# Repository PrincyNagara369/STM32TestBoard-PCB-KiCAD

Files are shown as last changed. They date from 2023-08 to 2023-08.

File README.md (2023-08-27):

# STM32TestBoard-PCB-KiCAD
Creating a PCB design for an STM32 test board using KiCad involves several steps. Below is a general outline of the process:

1. **Install KiCad:**
   If you haven't already, download and install the KiCad software from the official KiCad website (https://www.kicad-pcb.org/download/).

2. **Create a New Project:**
   - Open KiCad and create a new project for your STM32 test board.
   - Choose a suitable project name and location.

3. **Schematic Design:**
   - Start by creating a new schematic sheet in your project.
   - Add components to the schematic, including the STM32 microcontroller, power supply components, connectors, and any other peripherals you plan to include.
   - Connect the components by adding wires and creating appropriate nets.

4. **Component Libraries:**
   - Make sure you have the required component libraries for your components. KiCad comes with a set of default libraries, and you can also download additional libraries if needed.

5. **Footprint Assignment:**
   - Associate footprints with your schematic symbols. KiCad allows you to associate each component with a physical footprint used in the PCB layout.

6. **Schematic Annotation:**
   - Annotate the components on the schematic. KiCad will assign unique reference designators (e.g., U1, R1) to each component.

7. **Electrical Rule Check (ERC):**
   - Run an ERC to identify any potential connectivity or design rule errors in your schematic.

8. **Generate Netlist:**
   - Generate a netlist file from your schematic. The netlist is used to create the PCB layout.

9. **PCB Layout:**
   - Create a new PCB layout from the generated netlist.
   - Import footprints for your components or create custom footprints if necessary.
   - Place the components on the PCB layout, arranging them in a logical and organized manner.

10. **Connect Traces:**
    - Route the traces to connect the components according to your design.
    - Pay attention to signal integrity, power distribution, and ground plane.

11. **Design Rules Check (DRC):**
    - Run a DRC to ensure that your layout adheres to design rules such as minimum trace width, clearance, and other manufacturing specifications.

12. **Add Copper Pours and Planes:**
    - Create copper pours for power and ground connections.
    - Add ground and power planes if necessary for better signal integrity and noise reduction.

13. **3D Visualization:**
    - KiCad provides a 3D visualization tool that lets you preview your PCB in a realistic manner.

14. **Generate Gerber Files:**
    - Once you're satisfied with your PCB layout, generate the necessary Gerber files for manufacturing. These files include information about copper traces, solder mask, silkscreen, and more.

15. **Assembly Drawing:**
    - Create an assembly drawing that shows the component placements, reference designators, and other important details for assembling the PCB.

16. **Final Checks:**
    - Review your design thoroughly to ensure everything is correct and meets your requirements.

17. **Documentation:**
    - Create a documentation package that includes the schematic, PCB layout files, Gerber files, and any additional notes or instructions.

18. **Manufacturing:**
    - Send the Gerber files and other required documents to a PCB manufacturer for fabrication.

Remember that PCB design can be complex and requires attention to detail. It's also a good practice to consult the datasheets and reference manuals of your components, as well as any relevant PCB design guidelines from the microcontroller manufacturer. Additionally, there are many online resources, tutorials, and forums where you can find help and guidance during your KiCad PCB design journey.

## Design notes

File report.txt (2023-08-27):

Info: Reading netlist file 'C:\Users\Princy\Desktop\STM32F4_REV2\STM32F4_REV2.net'.

Info: Using reference designators to match symbols and footprints.

Info: Processing symbol 'J1:TerminalBlock_Phoenix:TerminalBlock_Phoenix_PT-1,5-2-3.5-H_1x02_P3.50mm_Horizontal'.
Info: Processing symbol 'R9:Resistor_SMD:R_0603_1608Metric'.
Info: Processing symbol 'R6:Resistor_SMD:R_0603_1608Metric'.
Info: Processing symbol 'R5:Resistor_SMD:R_0603_1608Metric'.
Info: Processing symbol 'R4:Resistor_SMD:R_0603_1608Metric'.
Info: Processing symbol 'R3:Resistor_SMD:R_0603_1608Metric'.
Info: Processing symbol 'R2:Resistor_SMD:R_0603_1608Metric'.
Info: Processing symbol 'R1:Resistor_SMD:R_0603_1608Metric'.
Info: Processing symbol 'R10:Resistor_SMD:R_0402_1005Metric'.
Info: Processing symbol 'R11:Resistor_SMD:R_0402_1005Metric'.
Info: Processing symbol 'R8:Resistor_SMD:R_0402_1005Metric'.
Info: Processing symbol 'R7:Resistor_SMD:R_0402_1005Metric'.
Info: Processing symbol 'U3:Package_TO_SOT_SMD:SOT-23-6'.
Info: Processing symbol 'U1:Package_TO_SOT_SMD:SOT-23-6'.
Info: Processing symbol 'Q1:Package_TO_SOT_SMD:SOT-23'.
Info: Processing symbol 'U2:Package_QFP:LQFP-64_10x10mm_P0.5mm'.
Info: Processing symbol 'H1:MountingHole:MountingHole_4.3mm_M4_Pad_Via'.
Info: Processing symbol 'H2:MountingHole:MountingHole_4.3mm_M4_Pad_Via'.
Info: Processing symbol 'H3:MountingHole:MountingHole_4.3mm_M4_Pad_Via'.
Info: Processing symbol 'H4:MountingHole:MountingHole_4.3mm_M4_Pad_Via'.
Info: Processing symbol 'D3:LED_SMD:LED_0603_1608Metric'.
Info: Processing symbol 'D4:LED_SMD:LED_0603_1608Metric'.
Info: Processing symbol 'L1:Inductor_SMD:L_Sunlord_MWSA0518S'.
Info: Processing symbol 'FB1:Inductor_SMD:L_0805_2012Metric'.
Info: Processing symbol 'L2:Inductor_SMD:L_0402_1005Metric'.
Info: Processing symbol 'F1:Fuse:Fuse_1206_3216Metric'.
Info: Processing symbol 'D2:Diode_SMD:D_SOD-123'.
Info: Processing symbol 'D1:Diode_SMD:D_SOD-123'.
Info: Processing symbol 'Y1:Crystal:Crystal_SMD_3225-4Pin_3.2x2.5mm'.
Info: Processing symbol 'J5:Connector_USB:USB_Micro-B_GCT_USB3076-30-A'.
Info: Processing symbol 'J2:Connector_PinSocket_1.27mm:PinSocket_2x05_P1.27mm_Vertical_SMD'.
Info: Processing symbol 'J3:Connector_Molex:Molex_PicoBlade_53048-0410_1x04_P1.25mm_Horizontal'.
Info: Processing symbol 'J4:Connector_Molex:Molex_PicoBlade_53048-0410_1x04_P1.25mm_Horizontal'.
Info: Processing symbol 'C1:Capacitor_SMD:C_1206_3216Metric'.
Info: Processing symbol 'C2:Capacitor_SMD:C_1206_3216Metric'.
Info: Processing symbol 'C3:Capacitor_SMD:C_1206_3216Metric'.
Info: Processing symbol 'C4:Capacitor_SMD:C_0603_1608Metric'.
Info: Processing symbol 'C14:Capacitor_SMD:C_0603_1608Metric'.
Info: Processing symbol 'C13:Capacitor_SMD:C_0603_1608Metric'.
Info: Processing symbol 'C5:Capacitor_SMD:C_0603_1608Metric'.
Info: Processing symbol 'C16:Capacitor_SMD:C_0402_1005Metric'.
Info: Processing symbol 'C15:Capacitor_SMD:C_0402_1005Metric'.
Info: Processing symbol 'C7:Capacitor_SMD:C_0402_1005Metric'.
Info: Processing symbol 'C12:Capacitor_SMD:C_0402_1005Metric'.
Info: Processing symbol 'C11:Capacitor_SMD:C_0402_1005Metric'.
Info: Processing symbol 'C10:Capacitor_SMD:C_0402_1005Metric'.
Info: Processing symbol 'C9:Capacitor_SMD:C_0402_1005Metric'.
Info: Processing symbol 'C8:Capacitor_SMD:C_0402_1005Metric'.
Info: Processing symbol 'C6:Capacitor_SMD:C_0402_1005Metric'.
Info: Processing symbol 'SW1:Button_Switch_SMD:SW_SPDT_PCM12'.

Info: Total warnings: 0, errors: 0.

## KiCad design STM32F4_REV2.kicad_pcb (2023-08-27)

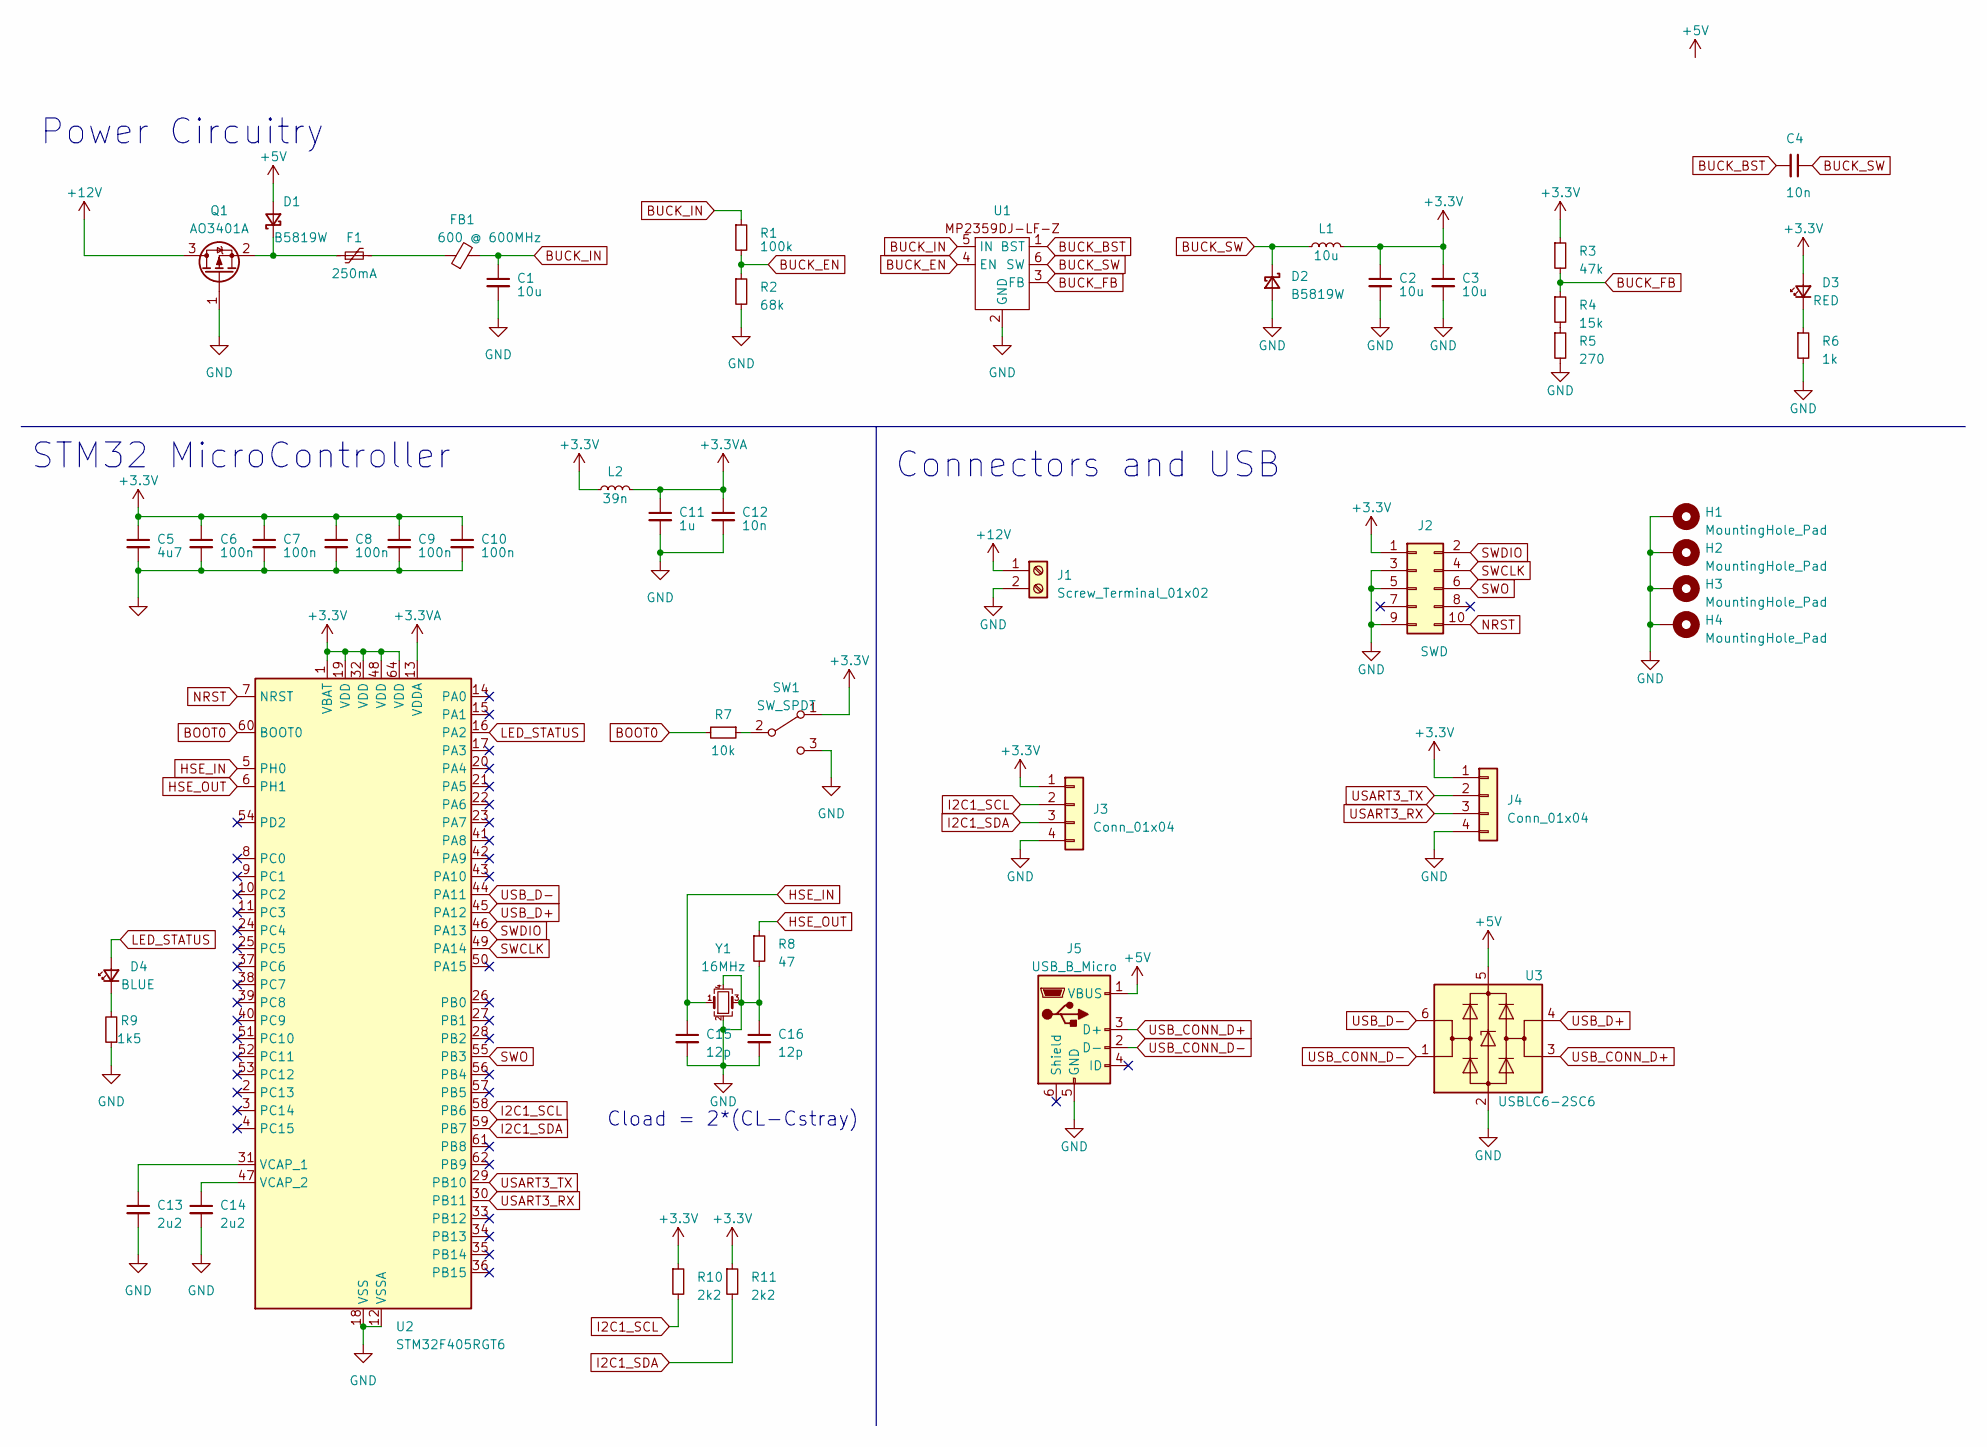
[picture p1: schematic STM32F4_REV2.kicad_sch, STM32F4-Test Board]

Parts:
C1, C2, C3: 10u; C_1206_3216Metric
C4: 10n; C_0603_1608Metric
C5: 4u7; C_0603_1608Metric
C6, C7, C8, C9, C10: 100n; C_0402_1005Metric
C11: 1u; C_0402_1005Metric
C12: 10n; C_0402_1005Metric
C13, C14: 2u2; C_0603_1608Metric
C15, C16: 12p; C_0402_1005Metric
D1, D2: B5819W; D_SOD-123
D3: RED; LED_0603_1608Metric
D4: BLUE; LED_0603_1608Metric
F1: 250mA; Fuse_1206_3216Metric
FB1: 600 @ 600MHz; L_0805_2012Metric
H1, H2, H3, H4: MountingHole_Pad; MountingHole_4.3mm_M4_Pad_Via
J1: Screw_Terminal_01x02; TerminalBlock_Phoenix_PT-1,5-2-3.5-H_1x02_P3.50mm_Horizontal
J2: SWD; PinHeader_2x05_P1.27mm_Vertical_SMD
J3, J4: Conn_01x04; Molex_PicoBlade_53048-0410_1x04_P1.25mm_Horizontal
J5: USB_B_Micro; USB_Micro-B_GCT_USB3076-30-A
L1: 10u; L_Sunlord_MWSA0518S
L2: 39n; L_0402_1005Metric
Q1: AO3401A; SOT-23
R1: 100k; R_0603_1608Metric
R2: 68k; R_0603_1608Metric
R3: 47k; R_0603_1608Metric
R4: 15k; R_0603_1608Metric
R5: 270; R_0603_1608Metric
R6: 1k; R_0603_1608Metric
R7: 10k; R_0402_1005Metric
R8: 47; R_0402_1005Metric
R9: 1k5; R_0603_1608Metric
R10, R11: 2k2; R_0402_1005Metric
SW1: SW_SPDT; SW_SPDT_PCM12
U1: SOT-23-6
U2: STM32F405RGT6; LQFP-64_10x10mm_P0.5mm
U3: USBLC6-2SC6; SOT-23-6
Y1: 16MHz; Crystal_SMD_3225-4Pin_3.2x2.5mm

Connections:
+3.3V: C2.1, C3.1, C5.1, C6.1, C7.1, C8.1, C9.1, C10.1, D3.2 (A), J2.1, J3.1, J4.1, L1.2, L2.1, R3.1, R10.1, R11.1, SW1.1 (A), U2.1 (VBAT), U2.19 (VDD), U2.32 (VDD), U2.48 (VDD), U2.64 (VDD)
+3.3VA: C11.1, C12.1, L2.2, U2.13 (VDDA)
+5V: D1.2 (A), J5.1 (VBUS), U3.5 (VBUS)
+12V: J1.1, Q1.3 (D)
BOOT0: R7.2, U2.60 (BOOT0)
BUCK_BST: C4.2, U1.1 (BST)
BUCK_EN: R1.2, R2.1, U1.4 (EN)
BUCK_FB: R3.2, R4.1, U1.3 (FB)
BUCK_IN: C1.1, FB1.2, R1.1, U1.5 (IN)
BUCK_SW: C4.1, D2.1 (K), L1.1, U1.6 (SW)
GND: C1.2, C2.2, C3.2, C5.2, C6.2, C7.2, C8.2, C9.2, C10.2, C11.2, C12.2, C13.2, C14.2, C15.2, C16.1, C16.2, D2.2 (A), H1.1, H2.1, H3.1, H4.1, J1.2, J2.3, J2.5, J2.9, J3.4, J4.4, J5.5 (GND), Q1.1 (G), R2.2, R5.2, R6.2, R8.2, R9.1, SW1.3 (C), U1.2 (GND), U2.12 (VSSA), U2.18 (VSS), U2.63 (VSS), U3.2 (GND), Y1.2, Y1.3, Y1.4
HSE_IN: C15.1, U2.5 (PH0), Y1.1
HSE_OUT: R8.1, U2.6 (PH1)
I2C1_SCL: J3.2, R10.2, U2.58 (PB6)
I2C1_SDA: J3.3, R11.2, U2.59 (PB7)
LED_STATUS: D4.2 (A), U2.16 (PA2)
NRST: J2.10, U2.7 (NRST)
unnamed: D1.1 (K), F1.1, Q1.2 (S)
unnamed: D3.1 (K), R6.1
unnamed: D4.1 (K), R9.2
unnamed: F1.2, FB1.1
unnamed: R4.2, R5.1
unnamed: R7.1, SW1.2 (B)
unnamed: C13.1, U2.31 (VCAP_1)
unnamed: C14.1, U2.47 (VCAP_2)
SWCLK: J2.4, U2.49 (PA14)
SWDIO: J2.2, U2.46 (PA13)
SWO: J2.6, U2.55 (PB3)
USART3_RX: J4.3, U2.30 (PB11)
USART3_TX: J4.2, U2.29 (PB10)
USB_CONN_D+: J5.3 (D+), U3.3 (I/O2)
USB_CONN_D-: J5.2 (D-), U3.1 (I/O1)
USB_D+: U2.45 (PA12), U3.4 (I/O2)
USB_D-: U2.44 (PA11), U3.6 (I/O1)

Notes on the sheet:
Connectors and USB
STM32 MicroController
Cload = 2*(CL-Cstray)
Power Circuitry

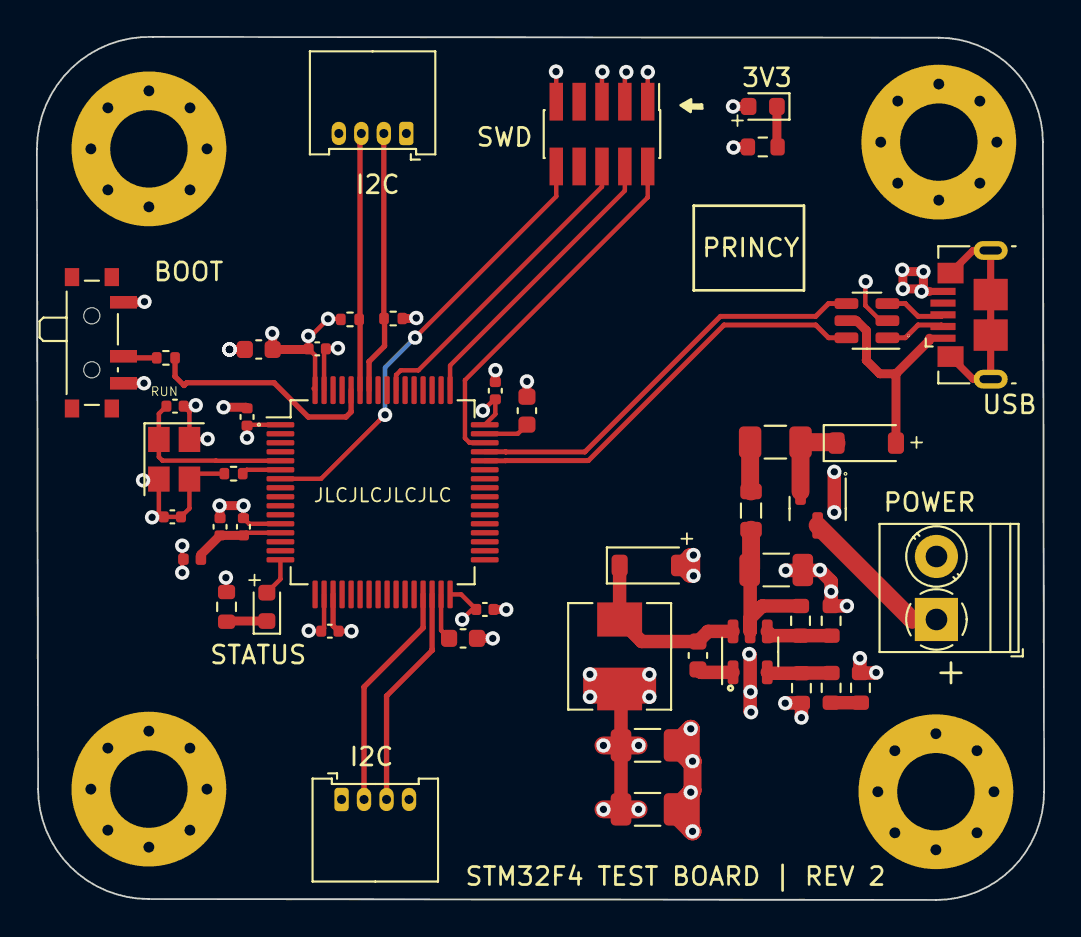
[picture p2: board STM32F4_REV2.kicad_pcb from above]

Board: 4 copper layers, 56.0 x 47.9 mm, 50 parts (0 on the bottom side), 34 nets.
